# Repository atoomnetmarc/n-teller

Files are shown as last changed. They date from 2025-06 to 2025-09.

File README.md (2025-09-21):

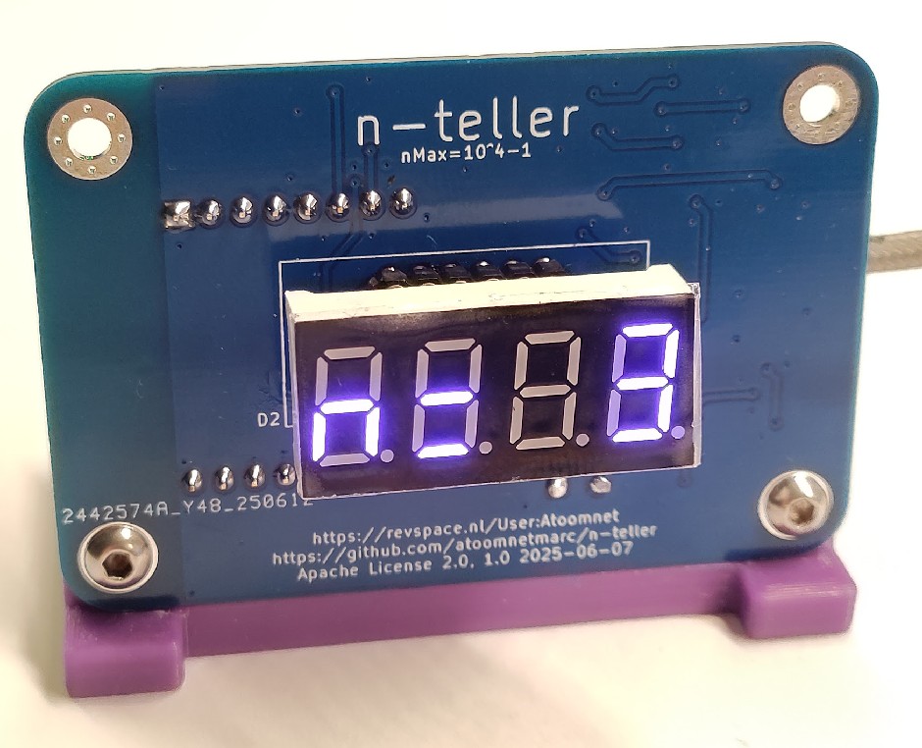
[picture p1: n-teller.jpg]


# n-teller

n-teller is an IoT device that displays the number of [checked in participants and visitors](https://revspace.nl/N) at the hackerspace called [Revelation Space (or RevSpace)](https://revspace.nl).

It connects to the [RevSpace MQTT server](https://revspace.nl/MQTT) via WiFi using an ESP8266.

The MQTT server publishes to [a few topics of interest](https://revspace.nl/MQTT#Topics) that are subscribed:

- revspace/[doorduino](https://revspace.nl/Doorduino3)/checked-in: this is the current total checked people.
- revspace/[state](https://revspace.nl/Spacestatus): the current state (open or closed) of the hackerspace.

# Schematic

[hardware/n-teller-schematic.pdf](hardware/n-teller-schematic.pdf)

# BOM

See interactive BOM: [hardware/bom/](https://html-preview.github.io/?url=https://github.com/atoomnetmarc/n-teller/blob/main/hardware/bom/ibom.html)

You will also need:

- The pcb. See [hardware/gerber/](hardware/gerber/) for gerber files.
- 2x M3x12 BHCS screws.
- Optional 1x [USB Type-C Female Chassis Connector](USB%20Type-C%20Female%20Chassis%20Connector.jpg).

# Render

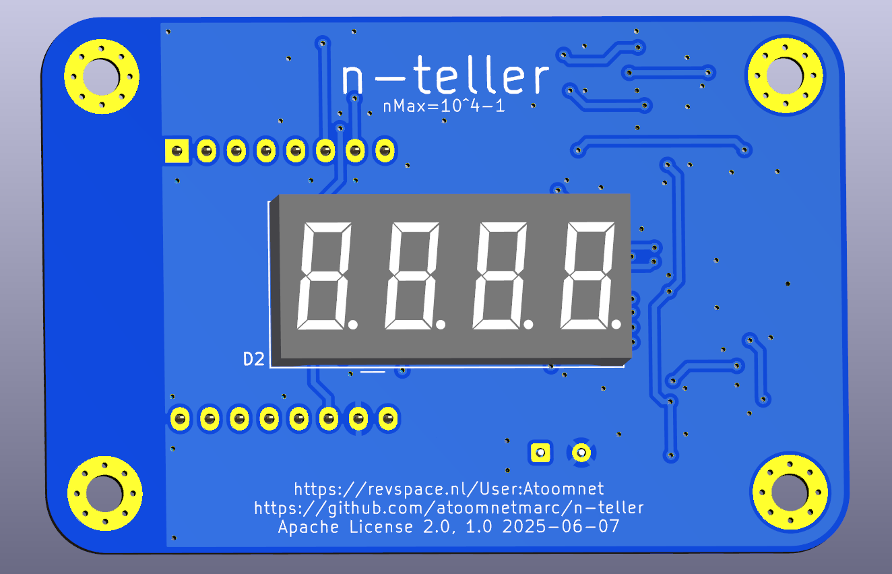
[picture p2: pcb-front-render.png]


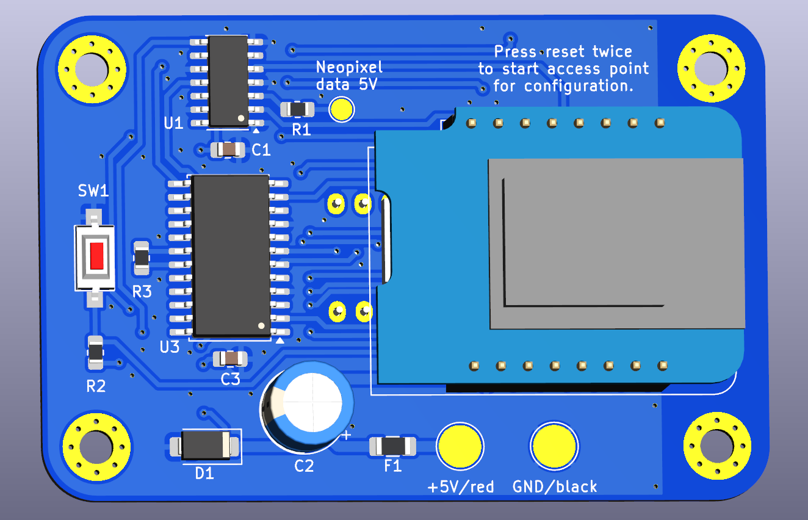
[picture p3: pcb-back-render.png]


# 3d-print

In the [3d](3d/) directory you can find a stand for the pcb.

Print `n-teller-stand-w-usb-c-socket.stl`. This will fit the optional USB Type-C Female Chassis Connector mentioned in the BOM. Or print `n-teller-stand.stl` and roll your own connection to 5V power supply.

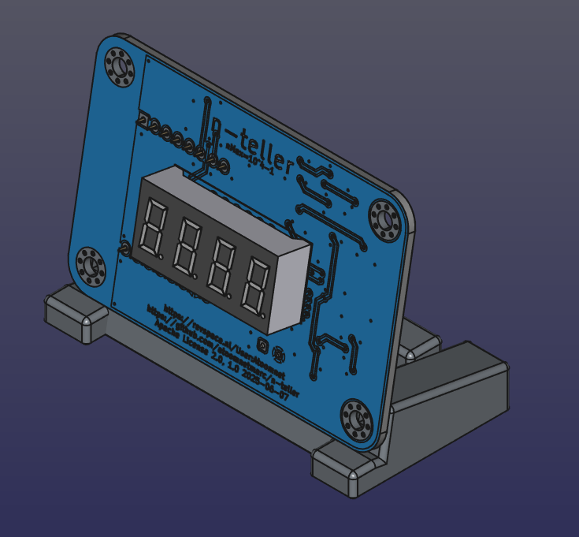
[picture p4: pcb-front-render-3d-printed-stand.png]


# Firmware

Compile and flash the firmware located in the [firmware directory](firmware/). You will need [PlatformIO](https://platformio.org/) for this. I recommend installing the [PlatformIO extension for VSCode](https://platformio.org/install/ide?install=vscode).

# Configure WiFi

Double press the reset button (somewhat slowly). The letters `AP` will appear on the display. Now connect to a WiFi network with a name like `nteller-bcddc2895fd2`. Then go to: http://192.168.4.1/ and configure your WiFi.

# Display information

PCB was designed to fit this type (pinout and dimensions) of 0.36" 4-digit 7-segment common cathode LED display:
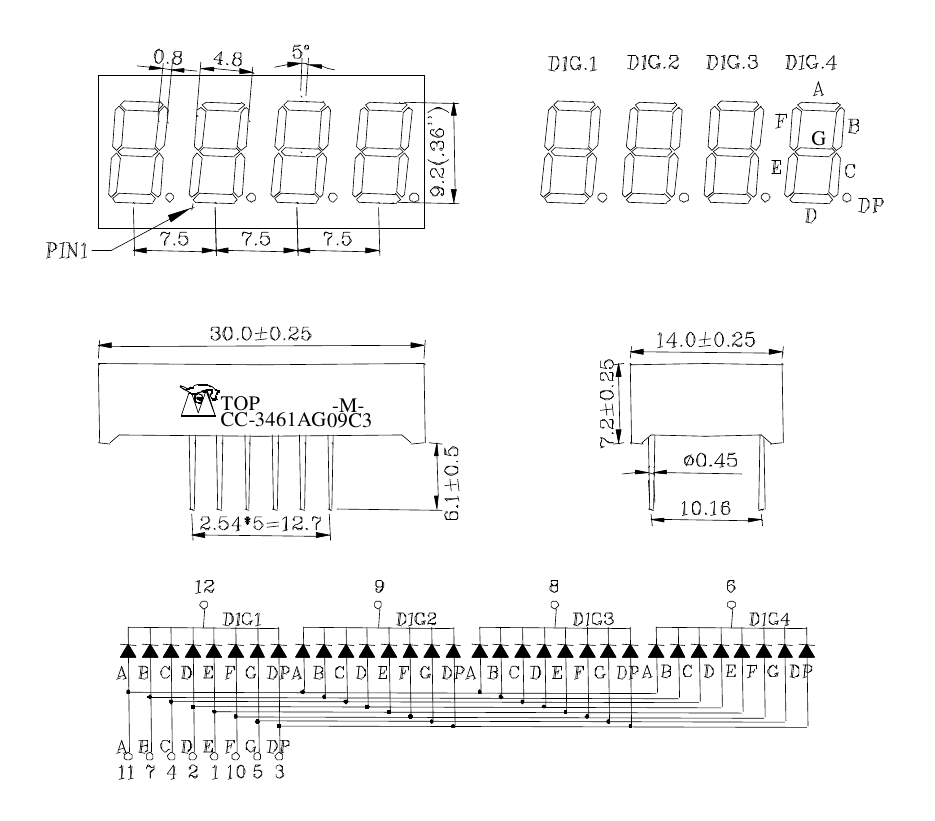
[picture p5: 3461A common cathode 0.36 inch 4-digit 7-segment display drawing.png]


## Model numbers and color options

| Model | Color | Tested |
| --- | --- | --- |
| LFD036AAG-101 | green |
| 3461AB | blue | :heavy_check_mark: |
| 3461AG | green |
| 3461AGG | jade green |
| 3461AO | orange |
| 3461AS | red |
| 3461AW | white |
| 3461AY | yellow |



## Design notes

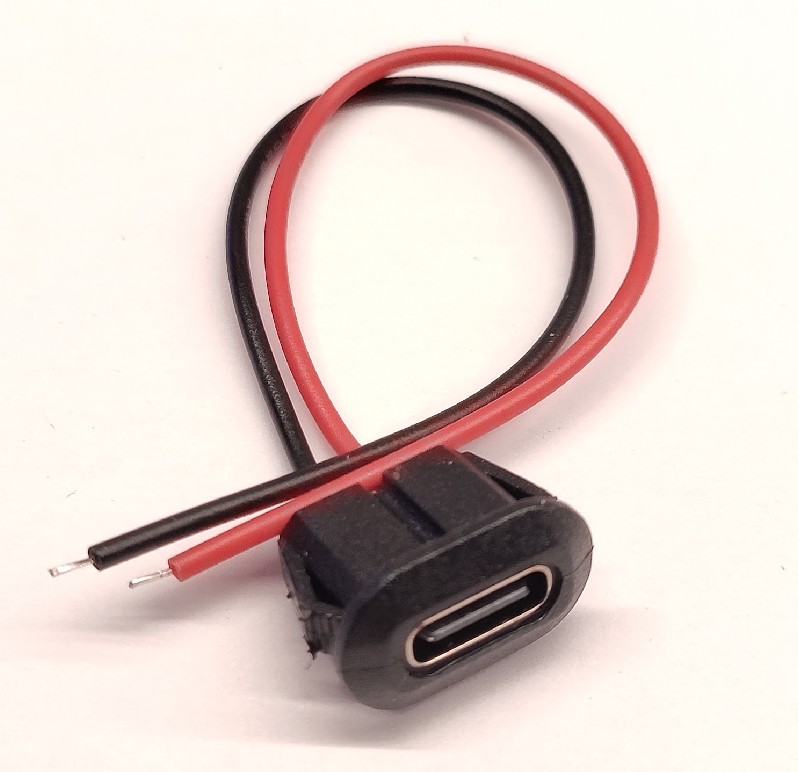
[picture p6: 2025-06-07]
USB Type-C Female Chassis Connector.jpg

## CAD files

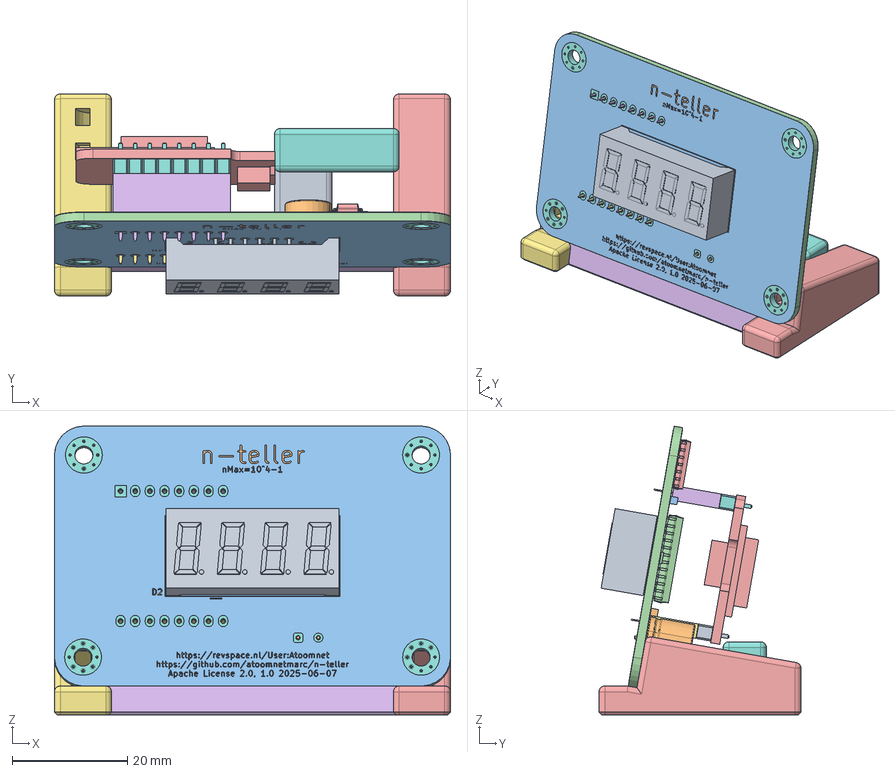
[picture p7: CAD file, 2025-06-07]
3d/n-teller-stand.FCStd
68.6 x 35.0 x 50.0 mm
SEVE_SEG_036INX4
CP_Radial_D8.0mm_P3.50mm
D_SMA
R_0805_2012Metric
WEMOS_D1_mini_light
PinSocket_1x08_P2.54mm_Vertical
PinSocket_1x08_P2.54mm_Vertical001
PinHeader_1x08_P2.54mm_Vertical
PinHeader_1x08_P2.54mm_Vertical001
C_0805_2012Metric
C_0805_2012Metric001
SOIC-24W_7.5x15.4mm_P1.27mm
SOIC-14_3.9x8.7mm_P1.27mm
Fuse_1206_3216Metric
n-teller_copper
n-teller_pad
n-teller_via
n-teller_silkscreen
n-teller_soldermask
n-teller_PCB
Foot-mirror
Footbridge
Foot-w-cuts
usb-c-socket
usb-c-socketbride

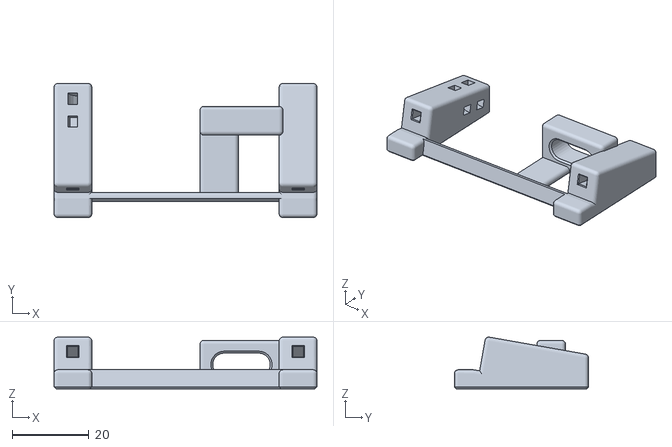
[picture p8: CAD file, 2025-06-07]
3d/n-teller-stand-w-usb-c-socket.stl
68.6 x 35.0 x 13.5

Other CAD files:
3d/n-teller-stand.stl

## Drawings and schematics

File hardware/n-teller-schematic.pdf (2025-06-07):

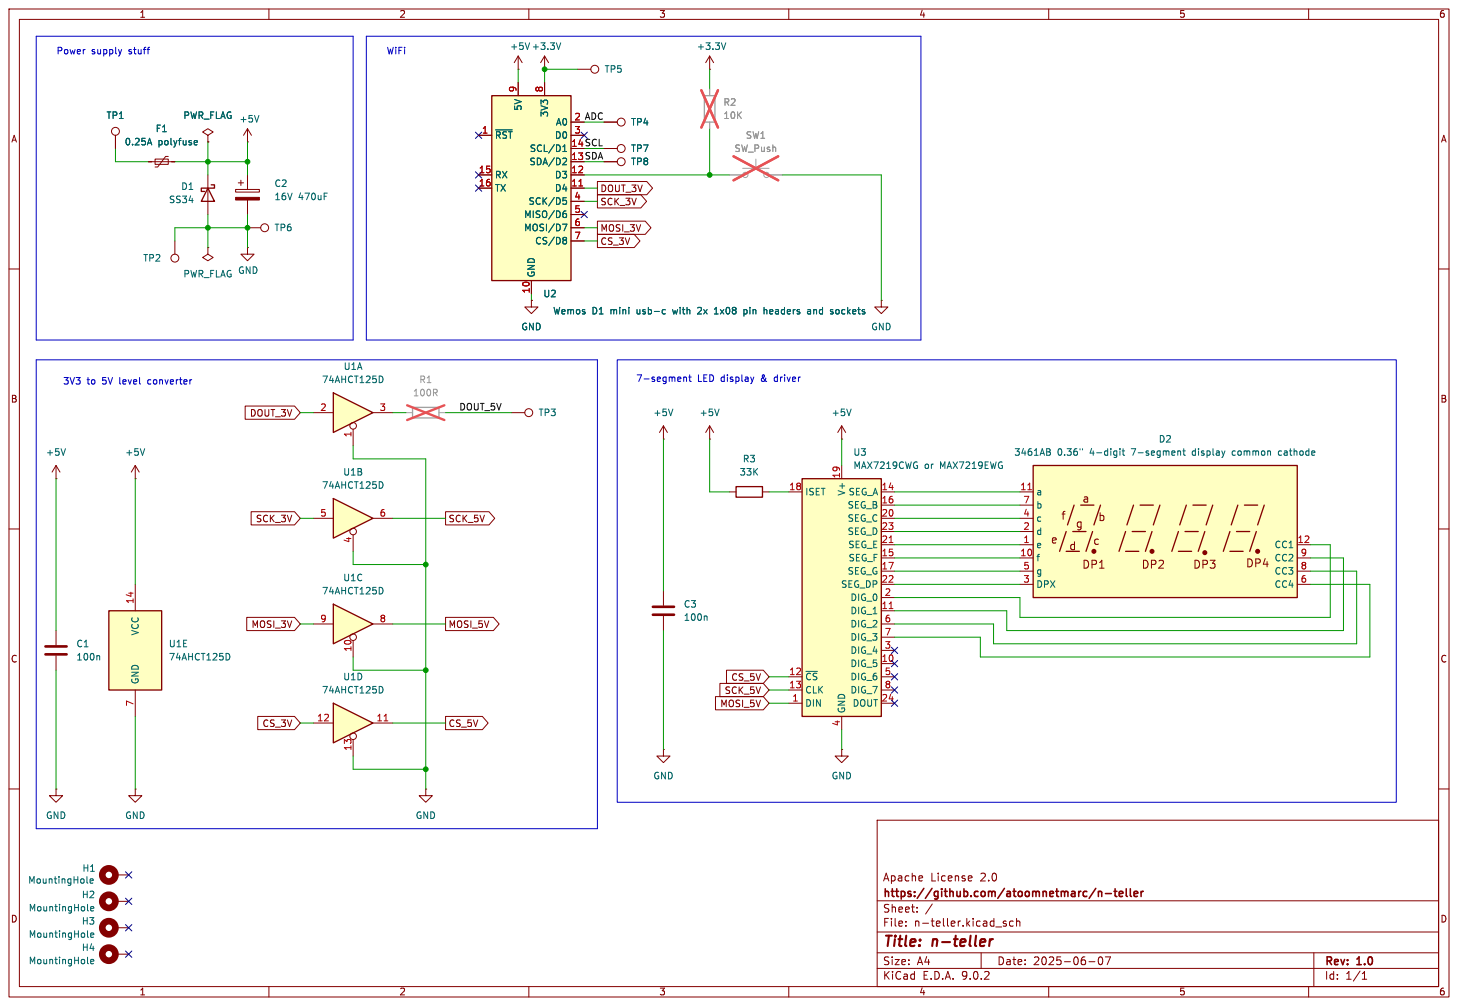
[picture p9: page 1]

8 A0 2 D0 3 SCL/D1 14 SDA/D2 13 D3 12 D4 11 SCK/D5 4 MISO/D6 5 MOSI/D7 6 CS/D8 7 U2Wemos D1 mini usb-c with 2x 1x08 pin headers and sockets +3.3V

8 A0 2 D0 3 SCL/D1 14 SDA/D2 13 D3 12 D4 11 SCK/D5 4 MISO/D6 5 MOSI/D7 6 CS/D8 7 GND

Apache License 2.0
Id: 1/1 Title: n-teller File: n-teller.kicad_sch Sheet: / https://github.com/atoomnetmarc/n-teller

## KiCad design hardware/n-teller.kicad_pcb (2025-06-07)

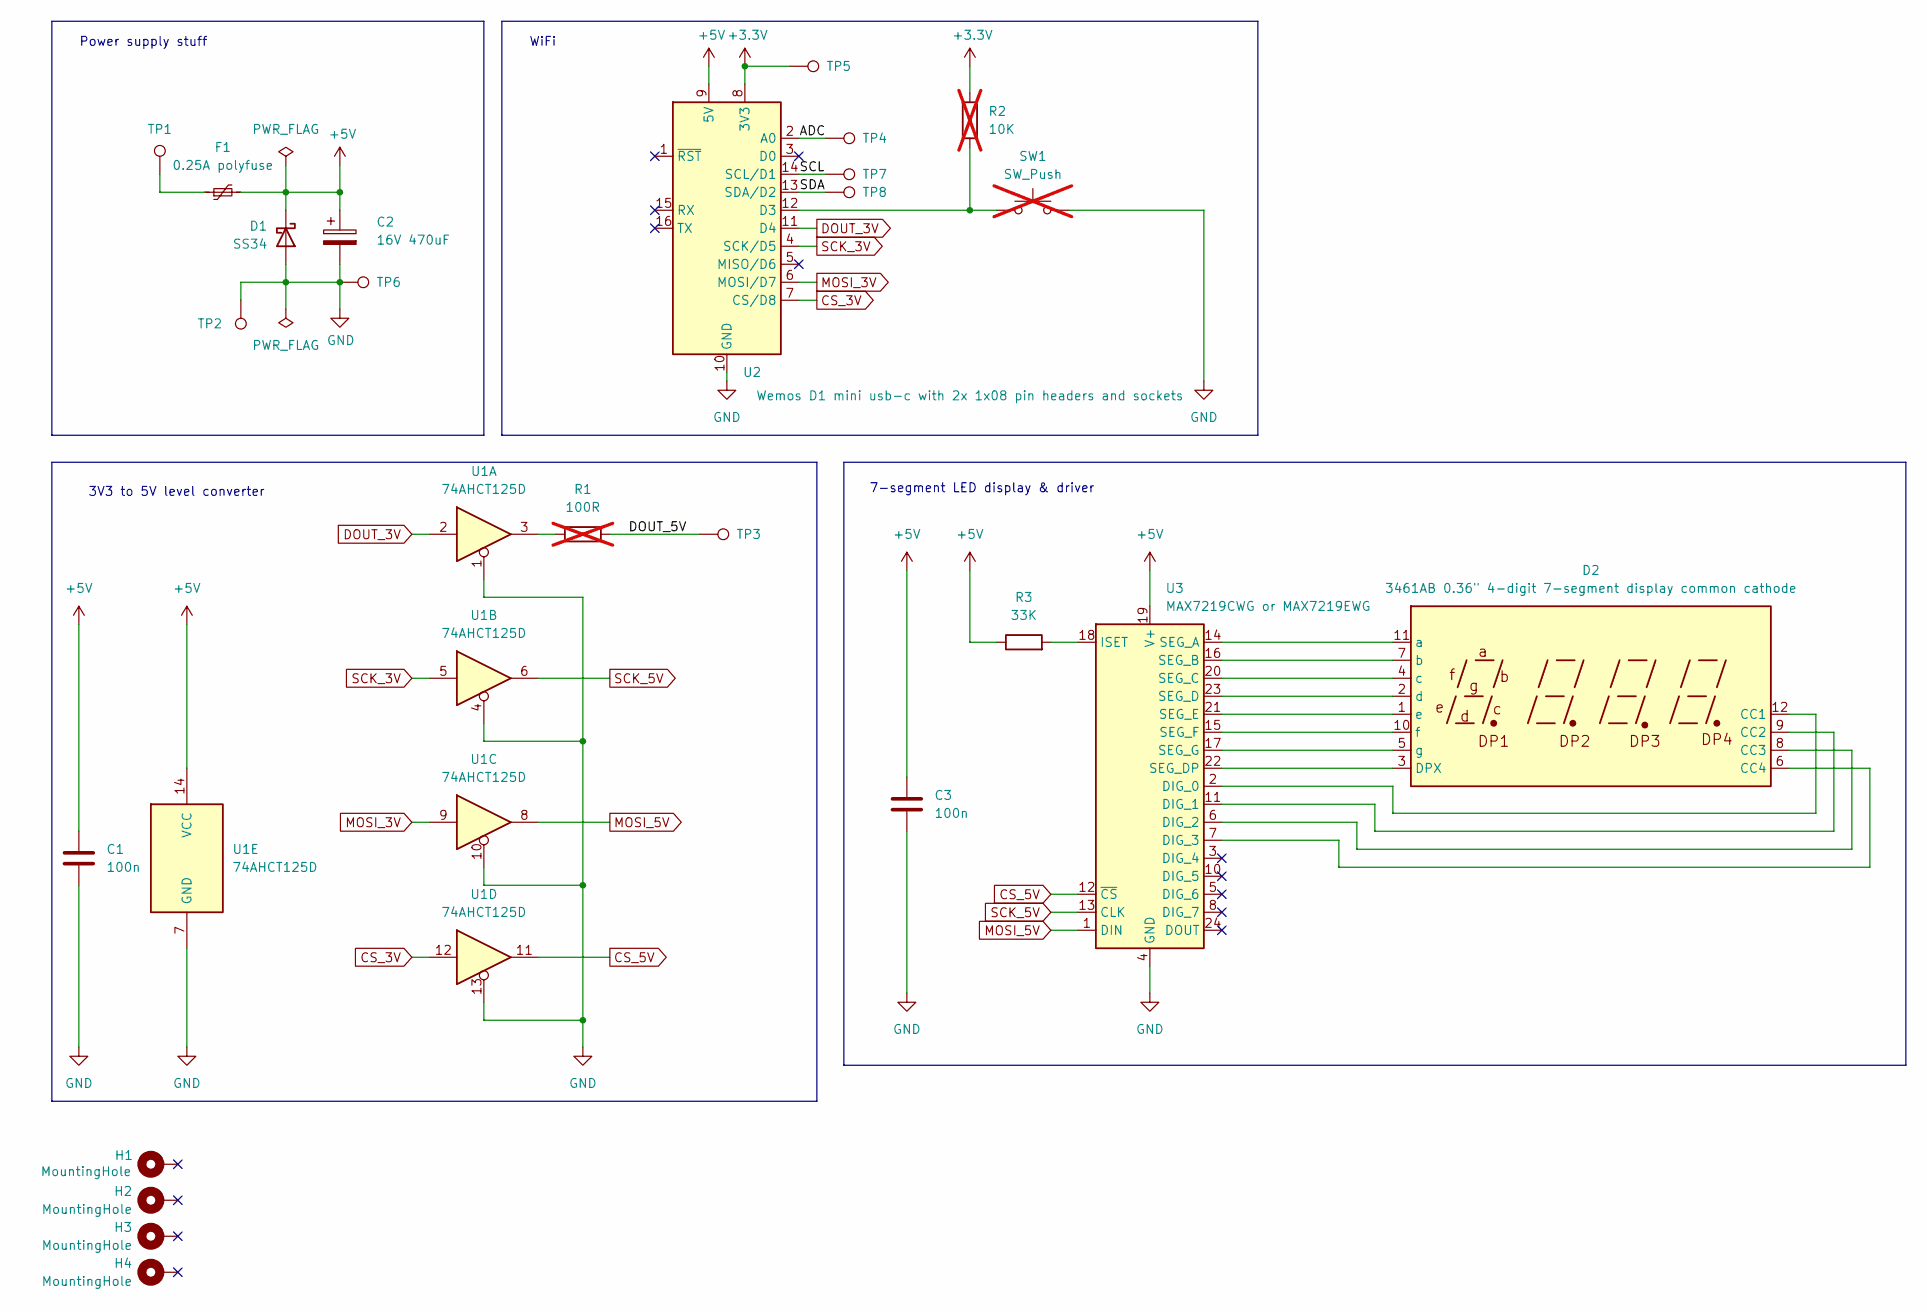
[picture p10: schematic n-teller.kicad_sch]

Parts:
C1, C3: 100n; C_0805_2012Metric_Pad1.18x1.45mm_HandSolder
C2: 16V 470uF; CP_Radial_D8.0mm_P3.50mm
D1: SS34; D_SMA
D2: 3461AB 0.36" 4-digit 7-segment display common cat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; 3461
F1: 0.25A polyfuse; Fuse_1206_3216Metric_Pad1.42x1.75mm_HandSolder
H1, H2, H3, H4: MountingHole; MountingHole_3.2mm_M3_Pad_Via
R1: 100R; R_0805_2012Metric_Pad1.20x1.40mm_HandSolder; not fitted
R2: 10K; R_0805_2012Metric_Pad1.20x1.40mm_HandSolder; not fitted
R3: 33K; R_0805_2012Metric_Pad1.20x1.40mm_HandSolder
SW1: SW_Push; SW_SPST_CK_RS282G05A3; not fitted
TP1, TP2: TestPoint; TestPoint_Pad_D4.0mm
TP3, TP4, TP5, TP6: TestPoint; TestPoint_Pad_D2.0mm
TP7, TP8: TestPoint; TestPoint_Pad_D1.0mm
U1: 74AHCT125D; SOIC-14_3.9x8.7mm_P1.27mm
U2: Wemos D1 mini usb-c with 2x 1x08 pin headers and 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; WEMOS_D1_mini
U3: MAX7219CWG or MAX7219EWG; SOIC-24W_7.5x15.4mm_P1.27mm

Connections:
+3.3V: R2.2, TP5.1, U2.8 (3V3)
+5V: C1.1, C2.1, C3.1, D1.1 (K), F1.2, R3.1, U1.14 (VCC), U2.9 (5V), U3.19 (V+)
/ADC: TP4.1, U2.2 (A0)
/DOUT_5V: R1.2, TP3.1
/SCL: TP7.1, U2.14 (SCL/D1)
/SDA: TP8.1, U2.13 (SDA/D2)
CS_3V: U1.12, U2.7 (CS/D8)
CS_5V: U1.11, U3.12 (~CS)
DOUT_3V: U1.2, U2.11 (D4)
GND: C1.2, C2.2, C3.2, D1.2 (A), SW1.1, TP2.1, TP6.1, U1.1, U1.4, U1.7 (GND), U1.10, U1.13, U2.10 (GND), U3.4 (GND), U3.9 (GND)
MOSI_3V: U1.9, U2.6 (MOSI/D7)
MOSI_5V: U1.8, U3.1 (DIN)
unnamed: D2.12 (CC1), U3.2 (DIG_0)
unnamed: D2.9 (CC2), U3.11 (DIG_1)
unnamed: D2.8 (CC3), U3.6 (DIG_2)
unnamed: D2.6 (CC4), U3.7 (DIG_3)
unnamed: D2.3 (DPX), U3.22 (SEG_DP)
unnamed: D2.11 (a), U3.14 (SEG_A)
unnamed: D2.7 (b), U3.16 (SEG_B)
unnamed: D2.4 (c), U3.20 (SEG_C)
unnamed: D2.2 (d), U3.23 (SEG_D)
unnamed: D2.1 (e), U3.21 (SEG_E)
unnamed: D2.10 (f), U3.15 (SEG_F)
unnamed: D2.5 (g), U3.17 (SEG_G)
unnamed: F1.1, TP1.1
unnamed: R1.1, U1.3
unnamed: R2.1, SW1.2, U2.12 (D3)
unnamed: R3.2, U3.18 (ISET)
SCK_3V: U1.5, U2.4 (SCK/D5)
SCK_5V: U1.6, U3.13 (CLK)

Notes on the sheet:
7-segment LED display & driver
3V3 to 5V level converter
Power supply stuff
WiFi

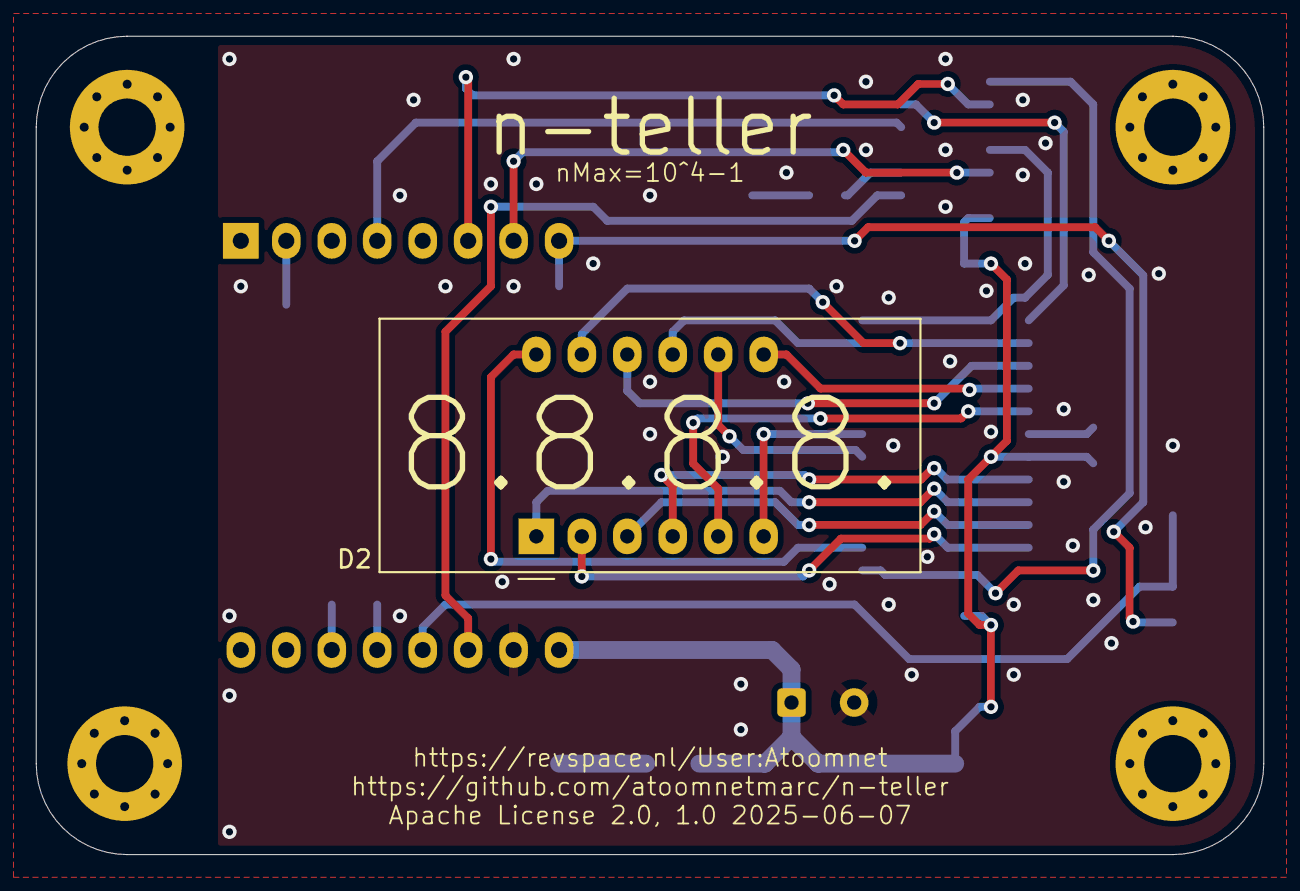
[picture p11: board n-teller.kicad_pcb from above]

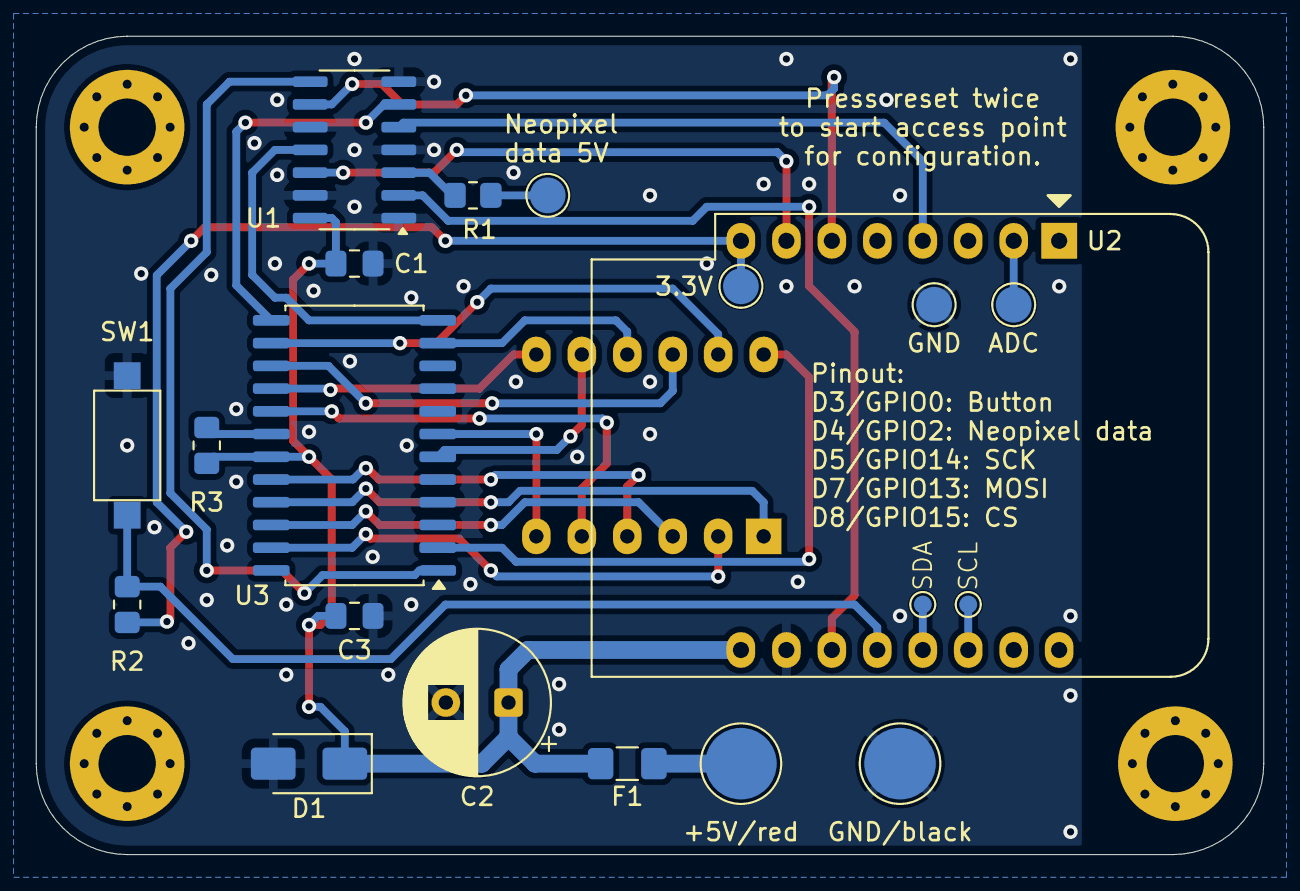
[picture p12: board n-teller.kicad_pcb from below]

Board: 2 copper layers, 68.6 x 45.7 mm, 25 parts (20 on the bottom side), 30 nets.

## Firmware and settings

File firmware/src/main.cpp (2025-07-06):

/*

Copyright 2025 Marc Ketel
SPDX-License-Identifier: Apache-2.0

*/

#include <Arduino.h>

#include <ESP8266WiFi.h>
#include <ESP8266mDNS.h>
#include <Ticker.h>

#include "DisplayManager.h"
#include <AsyncMqttClient.h>
#include <ESPAsyncWebServer.h>
#include <ESPAsyncWiFiManager.h>

#define ESP8266_DRD_USE_RTC       true
#define DOUBLERESETDETECTOR_DEBUG true
#define DRD_TIMEOUT               2
#define DRD_ADDRESS               0
#include <ESP_DoubleResetDetector.h>
DoubleResetDetector *drd;

DisplayManager display(13, 14, 15);

AsyncWebServer server(80);
DNSServer dns;

String name;

const char *mqtt_server = "revspace.nl";
AsyncMqttClient mqttClient;
Ticker mqttReconnectTimer;

WiFiEventHandler wifiConnectHandler;
WiFiEventHandler wifiDisconnectHandler;

void connectToMqtt() {
    Serial.println("Connecting to MQTT server");
    mqttClient.connect();
}

void onWifiConnect(const WiFiEventStationModeGotIP &event) {
    display.showText("viFi");
    Serial.println("WiFi connected.");
    connectToMqtt();
}

void onWifiDisconnect(const WiFiEventStationModeDisconnected &event) {
    Serial.println("WiFi has disconnected.");
    mqttReconnectTimer.detach();
}

void onMqttSubscribe(uint16_t packetId, uint8_t qos) {
    Serial.println("Subscription to topic acknowledged.");
}

void onMqttConnect(bool sessionPresent) {
    display.showText("MQtt");
    Serial.println("Connected to MQTT server.");
    Serial.println("Subscribing topics.");
    mqttClient.subscribe("revspace/doorduino/checked-in", 0);
    mqttClient.subscribe("revspace/state", 0);
}

void onMqttDisconnect(AsyncMqttClientDisconnectReason reason) {
    Serial.println("I seem to be disconnected from the MQTT server.");
    if (WiFi.isConnected()) {
        Serial.println("Lets reconnect to MQTT server.");
        mqttReconnectTimer.once(2, connectToMqtt);
    }
}

int16_t checkedin = 0;
uint8_t state = 0;

void onMqttMessage(char *topic, char *payload, AsyncMqttClientMessageProperties properties, size_t len, size_t index, size_t total) {
    String topicString = topic;

    Serial.print("A MQTT message has arrived on topic: ");
    Serial.println(topicString);

    // Do nothing if unexpected length is being published.
    if (len > 32) {
        Serial.println("Ignoring payload.");
        return;
    }

    Serial.print("MQTT payload: ");

    char payloadChars[len + 1];
    for (uint8_t i = 0; i < len; i++) {
        payloadChars[i] = payload[i];
    }
    payloadChars[len] = '\0';

    String payloadString = payloadChars;

    Serial.println(payloadString);

    if (topicString == "revspace/doorduino/checked-in") {
        checkedin = payloadString.toInt();
    }

    if (topicString == "revspace/state") {
        state = (payloadString == "open");
    }

    display.displayNumber(checkedin, state);
}

void setup() {
    drd = new DoubleResetDetector(DRD_TIMEOUT, DRD_ADDRESS);

    Serial.begin(115200);

    Serial.println("setup() starting.");

    String mac = WiFi.macAddress();
    mac.replace(":", "");
    mac.toLowerCase();
    name = "nteller-" + mac;

    Serial.print("Hello there! My hostname is ");
    Serial.println(name);

    Serial.println("Configuring MAX7219.");
    display.initialize();

    Serial.println("Starting WiFi.");
    WiFi.hostname(name.c_str());
    WiFi.setSleepMode(WIFI_NONE_SLEEP);

    if (drd->detectDoubleReset()) {
        Serial.println("Double reset detected. Starting wifimanager.");
        display.showText("_AP_");

        AsyncWiFiManager wifiManager(&server, &dns);
        wifiManager.setTimeout(300);
        if (!wifiManager.startConfigPortal(name.c_str())) {
            Serial.println("Failed to connect and hit timeout.");
            ESP.restart();
        }

        Serial.println("Our new WiFi credentials seem to work!");
    } else {
        WiFi.begin();
    }

    wifiConnectHandler = WiFi.onStationModeGotIP(onWifiConnect);
    wifiDisconnectHandler = WiFi.onStationModeDisconnected(onWifiDisconnect);

    mqttClient.onConnect(onMqttConnect);
    mqttClient.onDisconnect(onMqttDisconnect);
    mqttClient.onSubscribe(onMqttSubscribe);
    mqttClient.onMessage(onMqttMessage);
    mqttClient.setClientId(name.c_str());
    mqttClient.setServer(mqtt_server, 1883);

    if (!MDNS.begin(name.c_str())) {
        Serial.println("Error starting mDNS.");
    } else {
        Serial.println("mDNS started.");
    }

    Serial.println("Configuring async webserver.");
    server.on("/", HTTP_GET, [](AsyncWebServerRequest *request) {
        request->send(200, "text/plain", name);
    });

    Serial.println("setup() done.");
}

void loop() {
    MDNS.update();
    drd->loop();
}

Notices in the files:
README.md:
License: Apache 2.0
